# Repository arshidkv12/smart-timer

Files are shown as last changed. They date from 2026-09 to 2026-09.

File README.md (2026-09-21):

# Smart Timer Switch Using ESP8266 and RTC

A simple **Wi-Fi programmable timer switch** based on **ESP8266 and RTC**. It can automatically turn a connected device ON and OFF according to a configured schedule.

No internet connection is required. The timer creates its own local Wi-Fi network for configuration.

## Features

* 📡 ESP8266-based local Wi-Fi configuration
* ⏰ Real-time clock (RTC) for accurate timekeeping
* 🔌 5V relay for controlling electrical loads
* 🌐 Simple web-based configuration
* 🚫 No internet required
* 💾 Stores configuration locally
* 🔘 Physical button to enable configuration mode
* 📱 Configure using a mobile phone or computer

## Project Images

### Prototype

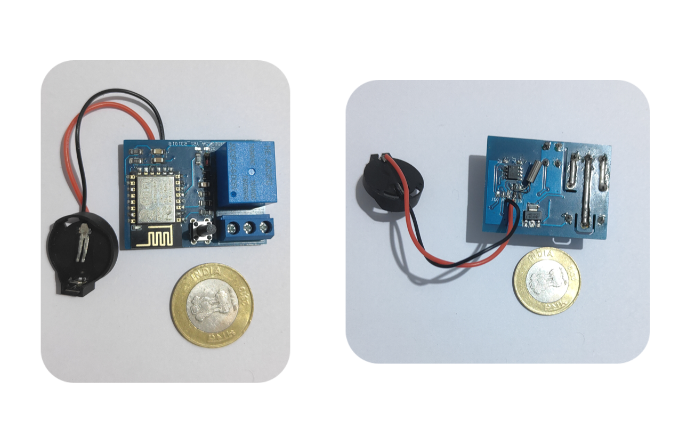
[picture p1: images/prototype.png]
Smart Timer Switch


### Circuit Diagram

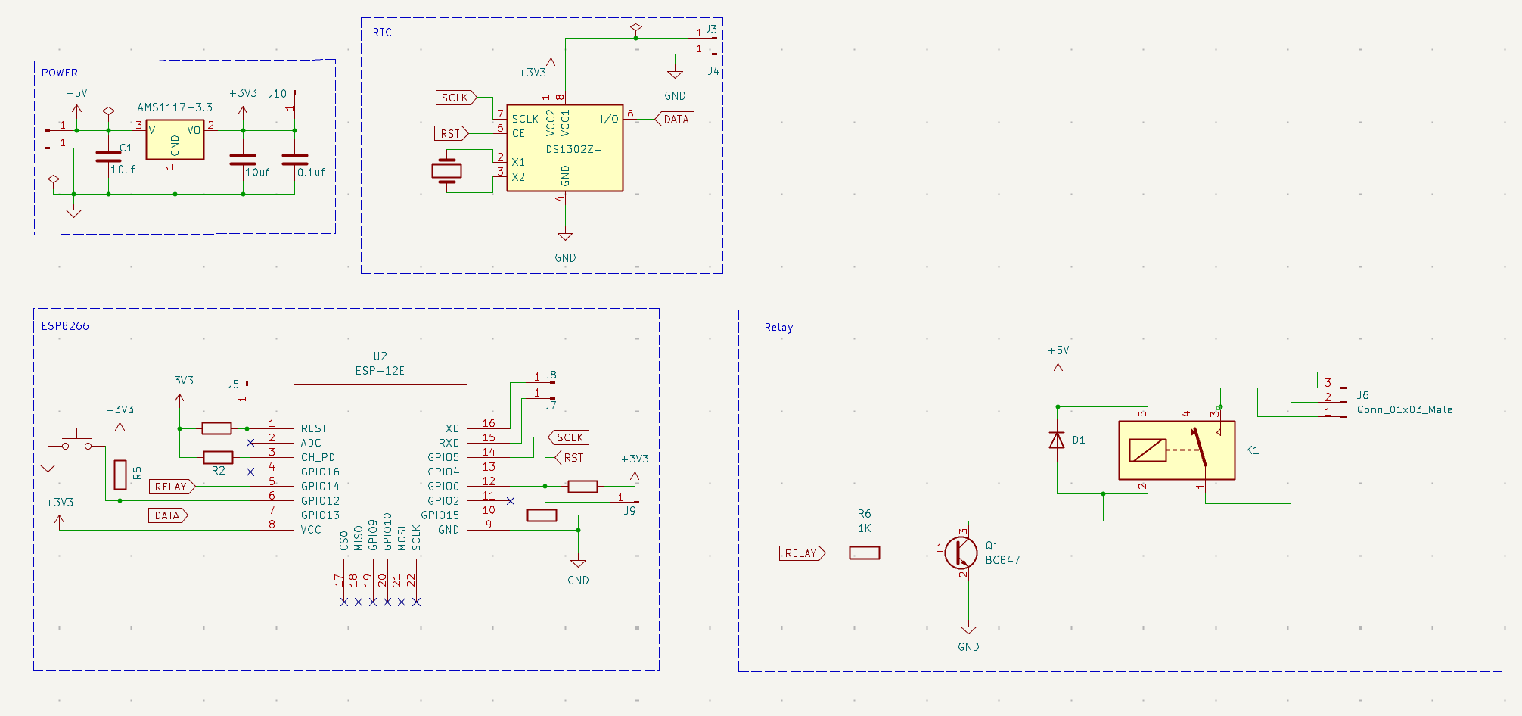
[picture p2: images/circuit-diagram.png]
Circuit Diagram


### Web Configuration

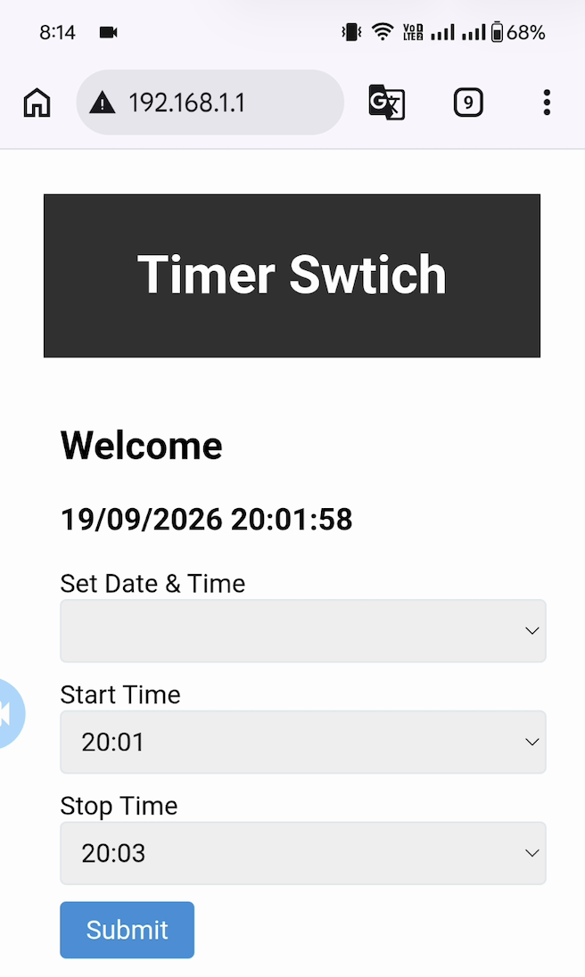
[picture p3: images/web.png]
Web Configuration


## YouTube

📺 **Watch the project demo:**  
▶️ [Watch the Smart Timer Switch Demo on YouTube](https://youtube.com/shorts/wJGOkK_HlXM)

## Main Blocks

The project mainly consists of four blocks:

1. **ESP8266** – Wi-Fi and controller
2. **5V Relay** – Controls the connected load
3. **Real-Time Clock (RTC)** – Keeps track of time
4. **Voltage Regulator** – Provides the required regulated voltage

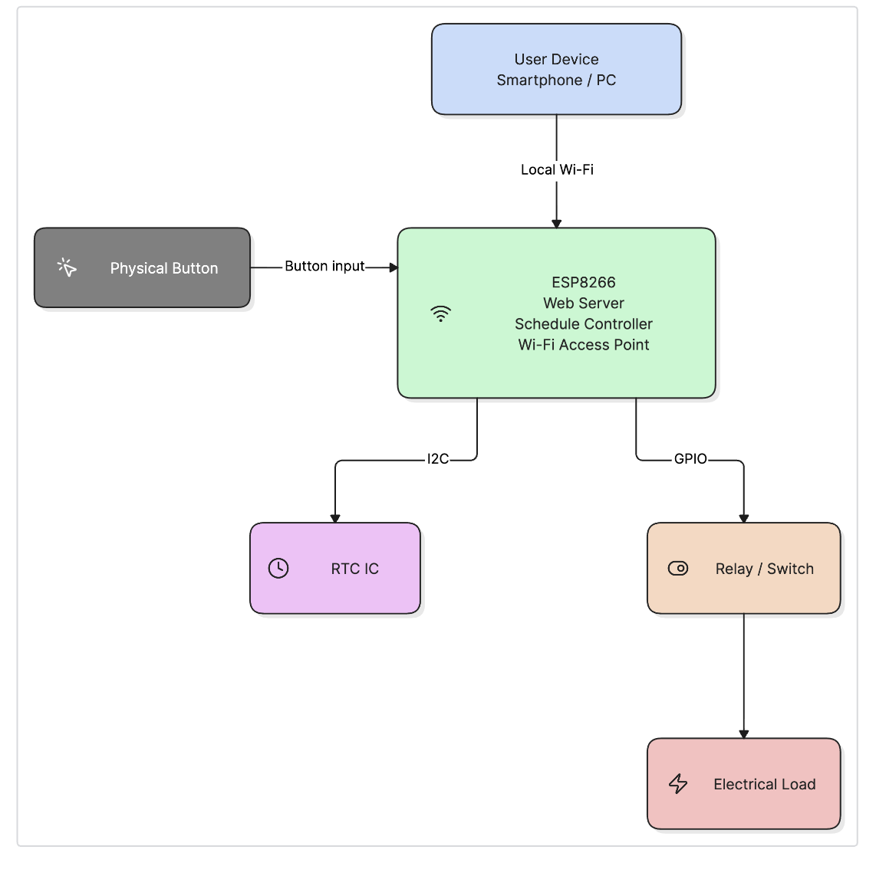
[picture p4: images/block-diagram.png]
Block Diagram


## How It Works

1. Power on the timer switch.
2. Press and hold the configuration button.
3. The ESP8266 enables local Wi-Fi mode.
4. Connect your phone or computer to the timer's Wi-Fi network.
5. Open a browser and go to:

```text
192.168.1.1
```

6. Set the current time if required.
7. Configure the ON and OFF schedule.
8. The timer automatically controls the connected load according to the schedule.

## Hardware

* ESP8266
* DS1302 RTC
* 5V Relay Module
* AMS1117-3.3V Voltage Regulator
* Push Button
* Resistors and capacitors
* Power supply
* Connected load

## Configuration

The timer uses a local web interface, so you don't need a cloud service or internet connection.

Connect to the timer's Wi-Fi, open `192.168.1.1` in your browser, and configure the required schedule.

## Example

For example:

```text
ON  → 08:01 PM
OFF → 08:03 PM
```

The relay will automatically switch the connected load according to the configured schedule.

## Advantages

* Simple configuration
* No internet dependency
* No LCD or LED display required
* Easy to modify the schedule
* Low-cost hardware
* Useful for automatic switching applications

## Project Structure

```text
├── firmware/
├── img/
│   ├── block-diagram.png
│   ├── diagram.png
│   ├── img.png
│   └── pcb.png
├── PCB/
├── README.md
└── project-report.pages
```

## License

This project is open source. See the `LICENSE` file for details.

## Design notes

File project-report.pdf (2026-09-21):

## Smart Offline Timer Switch: ESP8266-Based Programmable RTC Control

### Submitted By

## Muhammed Arshid KV

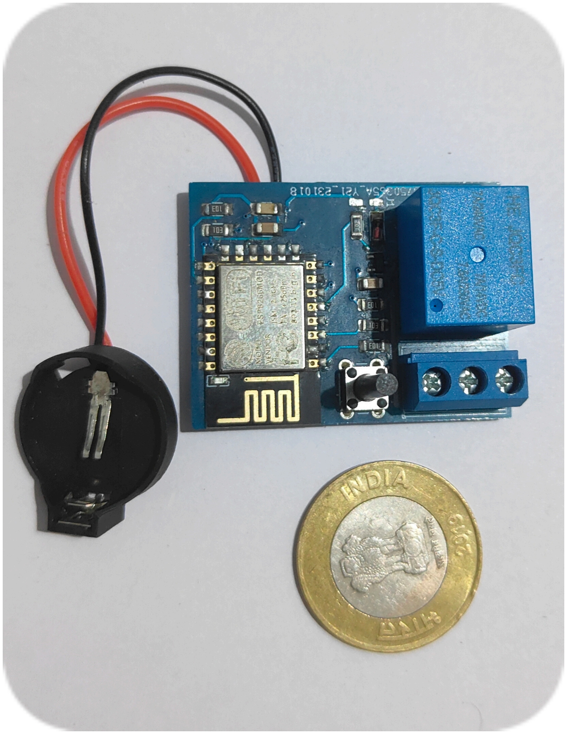
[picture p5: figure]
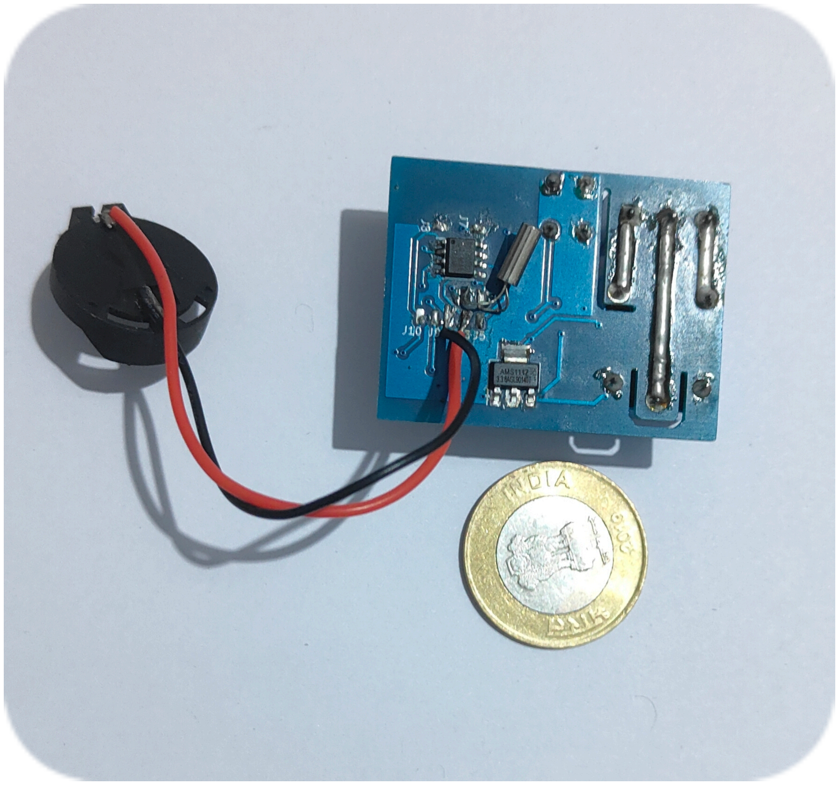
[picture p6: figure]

## 1. Abstract

This project presents the design and development of a Smart Programmable Timer Switch based on the ESP8266 microcontroller. The system is designed to control an electrical load according to user-defined schedules without requiring an internet connection.

Unlike conventional timer switches that use physical push-button configuration and 7-segment displays, configuring schedules through buttons can be difficult, while displays may require replacement over time. This system eliminates the need for a dedicated display by providing a simple web-based configuration interface.

The system operates completely offline. When configuration mode is activated by a long press of the physical button, the ESP8266 creates its own Wi-Fi access point. Users can connect directly to the device using a smartphone, tablet, or computer and access the web interface through: 192.168.1.1

Through the web interface, users can configure scheduled ON/OFF times and adjust the current RTC time when required.

A dedicated Real-Time Clock (RTC) IC maintains accurate time independently of the ESP8266's Wi-Fi connection or internet availability. Once the schedule is configured, the ESP8266 continuously monitors the RTC time and operates the connected electrical load according to the programmed schedule.

The system is suitable for applications such as lighting control, pumps, fans, agricultural equipment, aquarium systems, signage, and other appliances requiring scheduled operation.

## 2. Introduction

Automatic switching of electrical appliances at predefined times is useful in homes, commercial establishments, agriculture, and various industrial applications. Timer-based control can reduce manual effort and ensure that electrical loads operate according to a predetermined schedule.

Traditional timer switches are commonly configured using physical buttons, rotary controls, and small displays. Such interfaces can make schedule configuration inconvenient. Modern smart timer switches may provide more convenient smartphone-based control, but they often depend on internet connectivity, cloud services, mobile applications, user accounts, or continuous network availability.

The proposed system takes a different approach by providing simple local configuration without requiring the internet. The device uses an ESP8266 Wi-Fi microcontroller along with a dedicated Real-Time Clock (RTC) IC) to provide accurate time-based control.

To configure the device, the user simply presses and holds the physical button to activate configuration mode. The ESP8266 then creates its own Wi-Fi network, allowing a smartphone, tablet, or computer to connect directly to the device. The user can open a standard web browser and access the configuration interface at:

http://192.168.1.1

Through this interface, the user can configure the required ON/OFF schedules and adjust the RTC time when necessary. Since the device operates as its own Wi-Fi access point, no internet connection, mobile application, cloud account, or external Wi-Fi router is required for configuration.

Once the schedule is configured, the device can operate independently according to the programmed time settings, making it a practical solution for applications that require reliable and simple scheduled switching.

## 3. Objectives

The main objectives of this project are:

1. To develop an automatic programmable timer switch for scheduled electrical load control.
2. To eliminate the requirement for internet connectivity during configuration and operation.
3. To provide a simple browser-based interface for configuring the device.
4. To enable configuration using smartphones, tablets, or computers.
5. To use a dedicated RTC IC for accurate and reliable timekeeping.
6. To support multiple user-defined ON/OFF schedules.
7. To provide an option for manually adjusting the RTC time.
8. To minimize the number of physical controls required for configuration.
9. To eliminate the need for a dedicated display for schedule configuration.
10. To ensure that programmed schedules continue to operate even when the Wi-Fi configuration mode is inactive.
11. To develop a simple, reliable, and practical timer switch suitable for real-world applications.

## 4. Proposed System

The proposed system is a Smart Offline Programmable Timer Switch based on the ESP8266 microcontroller and a dedicated Real-Time Clock (RTC) IC. The system is designed to provide scheduled control of an electrical load without requiring an internet connection, external Wi-Fi router, or dedicated display.

The main components of the system are:

- ESP8266 microcontroller – Main controller of the system.
- RTC IC – Maintains the current date and time accurately.
- Switching circuit/relay – Controls the connected electrical load.
- Physical push button – Activates the configuration mode.
- Electrical load – The appliance or equipment controlled by the system.

The ESP8266 performs the following functions:

- Creates a local Wi-Fi access point for configuration.
- Hosts the configuration web interface.
- Receives user-defined schedules through the web interface.
- Reads the current date and time from the RTC.
- Stores and manages the programmed schedules.
- Compares the RTC time with the programmed schedules.
- Controls the switching circuit according to the scheduled ON/OFF times.

The RTC IC provides the current date and time independently of the Wi-Fi connection. After the

schedules are configured, the system can operate automatically based on the stored schedule even

when the configuration Wi-Fi mode is inactive.

When the physical button is pressed and held, the ESP8266 enters configuration mode and creates

its own Wi-Fi network. The user can connect to this network using a smartphone, tablet, or

computer and access the web-based configuration interface to set schedules or adjust the RTC time.

Basic architecture

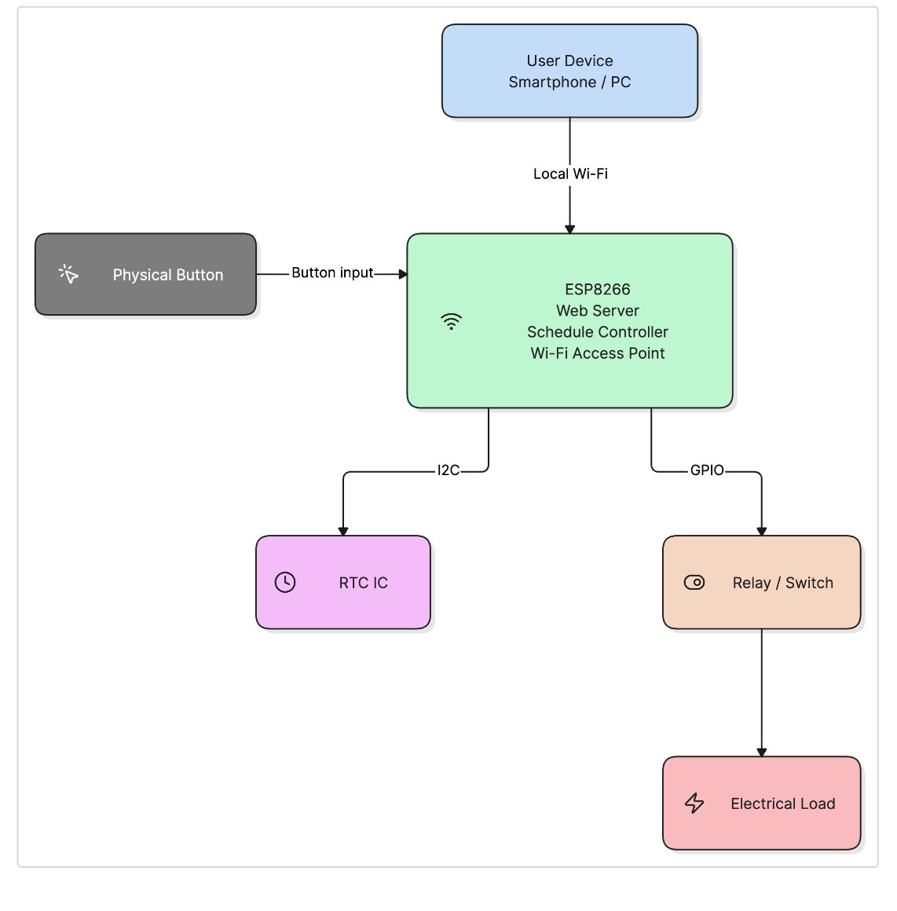
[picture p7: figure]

## 5. Hardware Components

The exact RTC IC and switching component can be specified according to the hardware version of the project.

## 6. Software Components

The software consists of several major modules.

ESP8266 firmware

The firmware is responsible for:

- Initializing hardware
- Reading the RTC
- Managing schedules
- Controlling the output
- Detecting long button presses
- Starting/stopping Wi-Fi configuration mode
- Running the web server
- Saving configuration data
Component | Function
ESP 8266 | Main microcontroller and Wi-Fi interface
RTC IC | Maintains accurate date and time
Relay / switching circuit | Controls the electrical load
Push button | Activates configuration mode
Power supply | Provides power to the electronics
RTC backup battery | Maintains RTC time during power interruptions
Electrical load | Appliance or device being controlled

Web interface

The embedded web server provides pages for:

- Current time
- RTC adjustment
- Schedule configuration
- ON/OFF settings
- Device status
- Configuration mode

The interface can be accessed using a normal web browser.

No dedicated Android or iOS application is required.

## 7. Operating Principle

The system operates in two primary modes.

Normal Operating Mode

During normal operation:

1. ESP8266 initializes the system.
2. The RTC provides the current time.
3. ESP8266 reads the programmed schedules.
4. The current time is compared with the schedule.
5. The output is switched ON or OFF accordingly.
6. Wi-Fi configuration mode remains inactive.
Therefore, the device can perform its main timer function without being connected to a network.

Configuration Mode

To configure the device:

1. The user presses and holds the physical button.
2. The ESP8266 detects the long press.
3. Configuration Wi-Fi is activated.
4. The ESP8266 creates its own wireless network.
5. The user connects a smartphone, tablet, or computer to the device.
6. The user opens a browser.
7. The user accesses 192.168.1.1.
8. The configuration page is displayed.
9. The user modifies schedules or RTC time.
10. The settings are stored.
11. Configuration mode can then be exited.

## 8. Offline Wi-Fi Configuration

One of the key features of the project is its internet-independent configuration system.

The ESP8266 works as a local access point.

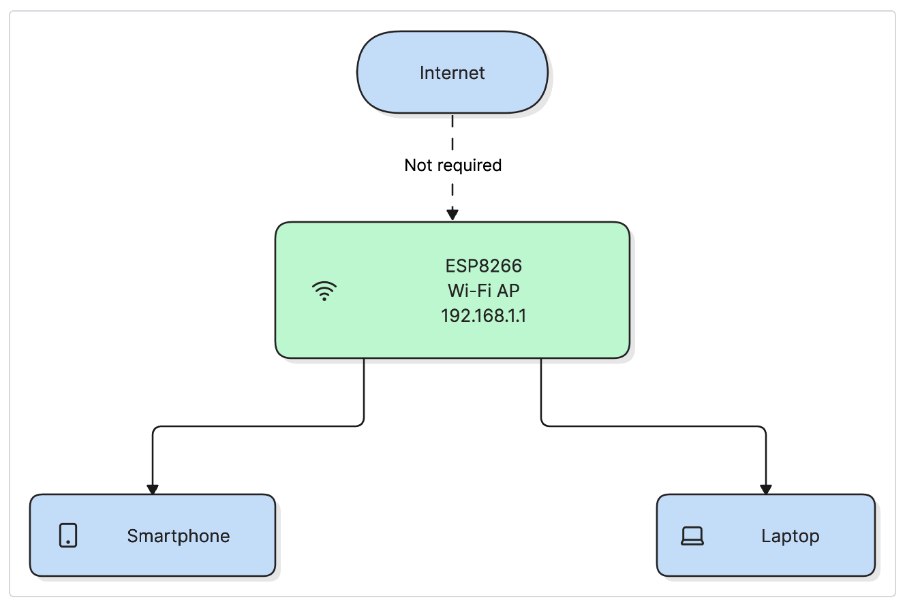
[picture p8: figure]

This means the user does not need:

- Internet
- Home Wi-Fi router
- Cloud server
- Mobile application
- Remote server
The phone communicates directly with the ESP8266.

## 9. Schedule Configuration

The user can define scheduled events through the web interface.

For example:

The ESP8266 continuously compares the RTC time with these programmed events.

For example:

06:00 ───── ON
08:00 ───── OFF
18:00 ───── ON
22:00 ───── OFF

This allows the same device to automatically control a load every day according to the programmed schedule.

## 10. RTC Time Adjustment

The RTC IC is an important part of the system because scheduled switching depends on accurate time.

The web interface provides an option to adjust the RTC time.

Schedule | Time | Action
1 | 06:00 | ON
2 | 08:00 | OFF
3 | 18:00 | ON
4 | 22:00 | OFF

The user can correct the RTC time whenever necessary.

The RTC's backup battery allows the clock to continue maintaining time when the main power supply is temporarily unavailable, depending on the RTC hardware used.

## 11. Long-Press Configuration Mechanism

A single physical button can be used to activate configuration mode.

Instead of keeping Wi-Fi active continuously, the device detects a long press.

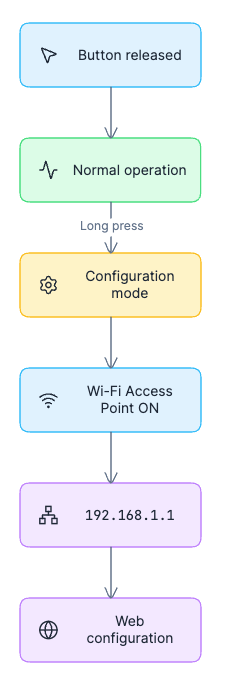
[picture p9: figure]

This approach has several benefits:

- Fewer physical controls
- Simple user interface
- Wi-Fi does not need to remain active
- Lower unnecessary power consumption
- Reduced exposure of the configuration interface during normal operation

## 12. Advantages

### 12.1 Internet-Independent Operation

The system does not require an internet connection for configuration or normal operation. This allows the timer to function independently in locations where internet access is unavailable.

### 12.2 Browser-Based Configuration

The timer can be configured using a standard web browser on a smartphone, tablet, laptop, or computer with Wi-Fi capability.

### 12.3 No Dedicated Mobile Application

No special mobile application needs to be installed. The web-based interface can be accessed directly through a standard browser.

### 12.4 Direct Local Communication

Communication takes place directly between the user's device and the ESP8266 through its local Wi-Fi network. No cloud server or external router is required.

### 12.5 RTC-Based Accurate Timing

A dedicated Real-Time Clock (RTC) IC provides reliable timekeeping for accurate execution of programmed schedules.

### 12.6 Simple Configuration

A physical long-press button is used to activate configuration mode, providing a simple method of accessing the web interface without requiring multiple physical buttons or a dedicated display.

### 12.7 Automatic Operation

After the required schedules are programmed, the system automatically controls the connected electrical load according to the configured ON/OFF times without continuous user intervention.

### 12.8 Low-Cost Implementation

The ESP8266 integrates Wi-Fi functionality and microcontroller capabilities into a compact and relatively low-cost platform, reducing the overall hardware complexity of the system.

### 12.9 No Dedicated Display Required

The web-based interface eliminates the need for a dedicated display such as a 7-segment display for configuring and viewing timer settings, reducing hardware requirements and simplifying the design.

## 13. Applications

The Smart Offline Programmable Timer Switch can be used in a wide range of applications where scheduled control of electrical equipment is required. Possible applications include:

- Home and garden lighting
- Automatic water pumps
- Aquarium equipment
- Fans and ventilation systems
- Shop and commercial lighting
- Signboards and display lighting
- Agricultural equipment
- Irrigation systems
- Poultry equipment
- Greenhouse equipment
- Decorative lighting
- Industrial auxiliary equipment
- Battery charging systems
- Energy-saving automation
- Other electrical appliances requiring scheduled ON/OFF operation

## 14. Security Considerations

Since the configuration interface is accessible through a local Wi-Fi network, appropriate security measures should be considered to prevent unauthorized configuration.

Possible security measures include:

- Enable configuration mode only after a long press of the physical button.
- Use a configurable password for the Wi-Fi access point.
- Protect the web interface using authentication.
- Automatically disable configuration mode after a predefined timeout.
- Validate all values received through the web interface.
- Prevent unauthorized or arbitrary commands from being executed through HTTP parameters.
- Restrict configuration requests to the local device.
- Provide a physical reset mechanism when required.

The configuration Wi-Fi can also be automatically disabled after a predefined period of inactivity, reducing the time during which the configuration interface is accessible.

## 15. Reliability

A major design objective of the system is that scheduled timer operation should not depend on Wi-Fi or internet availability.

The architecture can therefore be divided into two independent functions:

### 15.1 Configuration Function

The ESP8266 provides a local Wi-Fi access point and web interface only when configuration mode is activated. The user can configure schedules and adjust the RTC time through a web browser.

### 15.2 Timer Control Function

The RTC continuously maintains the current time, while the ESP8266 compares the RTC time with the programmed schedules and controls the switching circuit accordingly. Once the configuration mode is disabled, the timer can continue its scheduled operation without an active Wi-Fi connection.

This separation improves the reliability of the system because temporary unavailability of Wi-Fi does not prevent the programmed timer from controlling the connected electrical load.

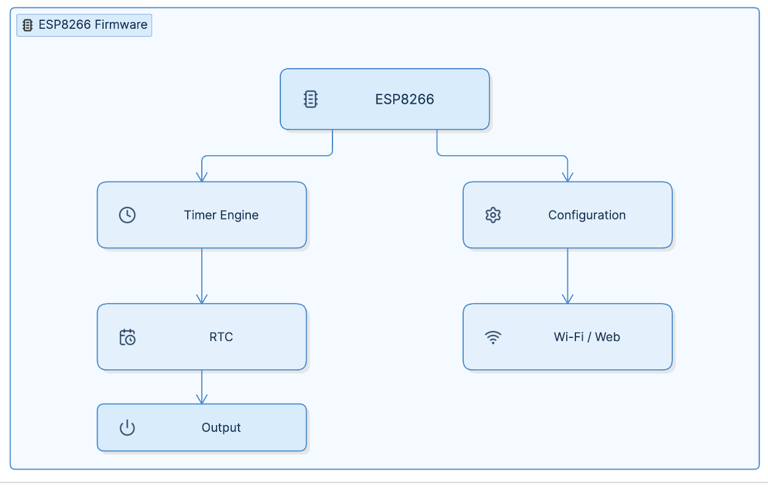
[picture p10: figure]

## 16. Limitations

Some limitations of the current design may include:

1. The user must be physically near the device to configure it.
2. Remote control is not available unless additional networking functionality is implemented.
3. RTC accuracy depends on the selected RTC IC and its oscillator.
4. The maximum number of schedules depends on firmware and available memory.
5. The electrical switching circuit must be appropriately rated for the connected load.
6. Mains-voltage hardware requires appropriate electrical isolation and safety precautions.

## 17. Future Improvements

The project can be extended with several features.

Multiple outputs

The system could control multiple relays independently.

Weekly schedules

Different schedules could be configured for Monday–Sunday.

Holiday/date-specific schedules

Specific dates could have different switching behavior.

Sunrise/sunset scheduling

The device could calculate switching times based on location and date, although this would require additional configuration/data.

Energy monitoring

Current and voltage sensors could be added to measure power consumption.

Manual control

The physical button could also provide manual ON/OFF control.

Configuration backup

Schedules could be exported and imported through the web interface.

Password protection

The configuration interface could require a username/password or PIN.

## 18. Conclusion

The Smart Offline Programmable Timer Switch using ESP8266 and RTC demonstrates how modern embedded technology can be used to provide convenient web-based configuration without depending on the internet or cloud services.

The ESP8266 provides the processing capability and local Wi-Fi connectivity, while the RTC IC provides reliable timekeeping for scheduled operation. A long-press physical button provides a simple method for entering configuration mode. Once activated, users can connect directly to the device using a smartphone, tablet, or computer and configure the timer through a standard web browser at 192.168.1.1.

The system combines embedded control, local Wi-Fi communication, web-based configuration, real-time clock functionality, and scheduled switching into a compact and practical solution. Since normal timer operation does not require an active Wi-Fi connection or internet access, the system can continue executing programmed schedules independently.

The elimination of a dedicated display and multiple configuration buttons also simplifies the hardware design and provides a more convenient configuration method through a web browser.

Project Highlights

ESP8266 + RTC + Local Web Interface + Scheduled Switching + No Internet Required

The core concept of the project can be summarized as:

“A Wi-Fi programmable timer that works without the internet.”

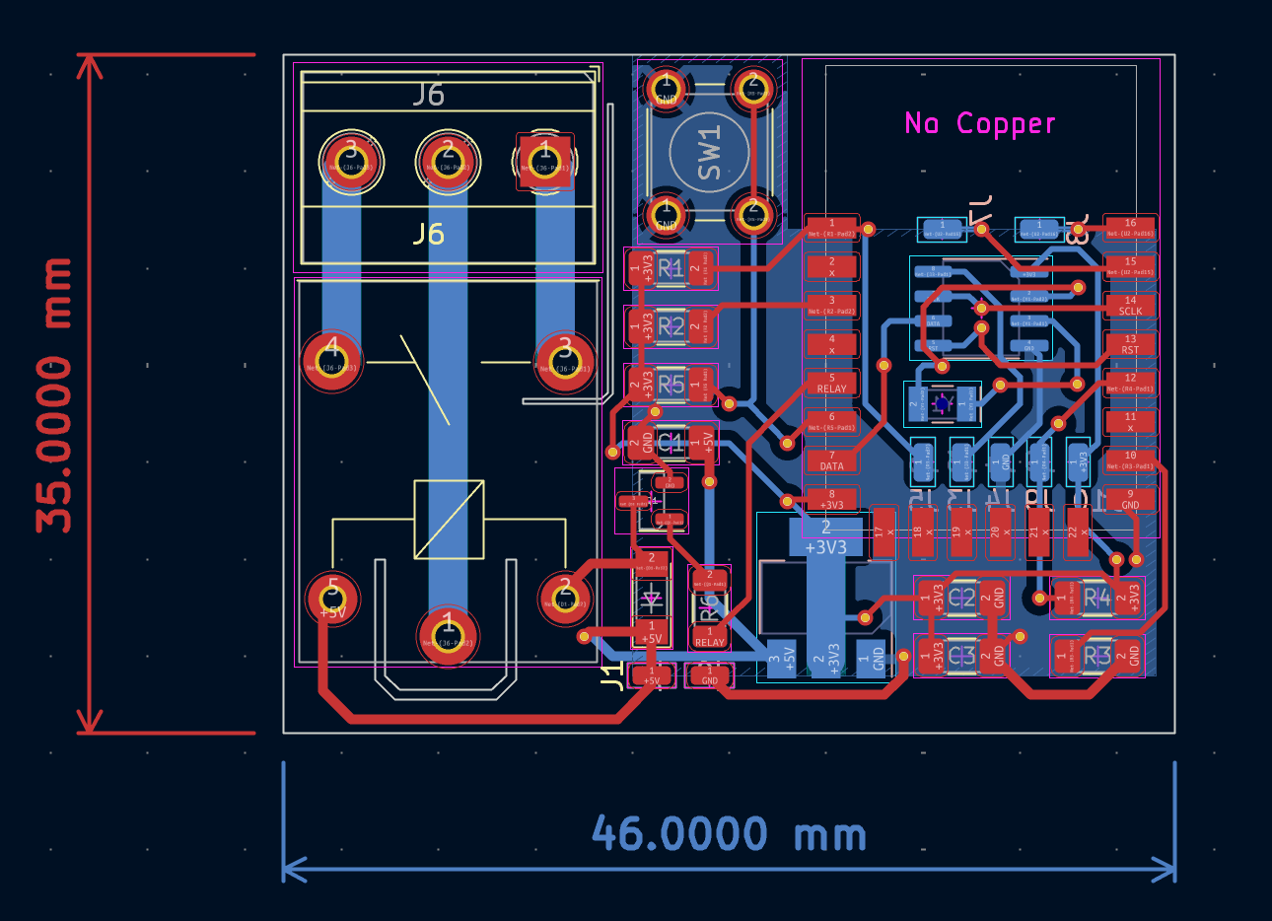
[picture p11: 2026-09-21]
images/pcb.png

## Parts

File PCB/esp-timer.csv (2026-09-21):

Comment | Designator | Footprint | LCSC Part #
10uf Unpolarized capacitor | C1,C2 | C_1206_3216Metric_Pad1.33x1.80mm_HandSolder
0.1uf Unpolarized capacitor | C3 | C_1206_3216Metric_Pad1.33x1.80mm_HandSolder
1N4007 1000V 1A General Purpose Rectifier Diode, DO-41 | D1 | D_MiniMELF
Conn_01x01_Male Generic connector, single row, 01x01, script generated (kicad-library-utils/schlib/autogen/connector/) | J1,J2,J3,J4,J5,J7,J8,J9,J10 | SolderWirePad_1x01_SMD_1x2mm
Conn_01x03_Male Generic connector, single row, 01x03, script generated (kicad-library-utils/schlib/autogen/connector/) | J6 | TerminalBlock_Phoenix_MKDS-1,5-3_1x03_P5.00mm_Horizontal
SANYOU_SRD_Form_C Sanyo SRD relay, Single Pole Miniature Power Relay, | K1 | Relay_SPDT_SANYOU_SRD_Series_Form_C
BC847 0.1A Ic, 45V Vce, Small Signal NPN Transistor, TO-92 | Q1 | SOT-23
R Resistor | R1,R2,R3,R4,R5 | R_1206_3216Metric_Pad1.30x1.75mm_HandSolder
1K Resistor | R6 | R_1206_3216Metric
SW_Push Push button switch, generic, two pins | SW1 | SW_PUSH_6mm_H13mm
AMS1117-3.3 1A Low Dropout regulator, positive, 3.3V fixed output, SOT-223 | U1 | SOT-223-3_TabPin2
ESP-12E ESP8266 ESP-12E module, 22 pins, 2mm, PCB antenna | U2 | ESP-12E_SMD
DS1302Z+ Trickle-Charge Timekeeping Chip, 2.0V to 5.5V VCC, 0°C to +70°C, SOIC-8 | U3 | SOIC-8_3.9x4.9mm_P1.27mm
Crystal Two pin crystal | Y1 | Crystal_SMD_G8-2Pin_3.2x1.5mm

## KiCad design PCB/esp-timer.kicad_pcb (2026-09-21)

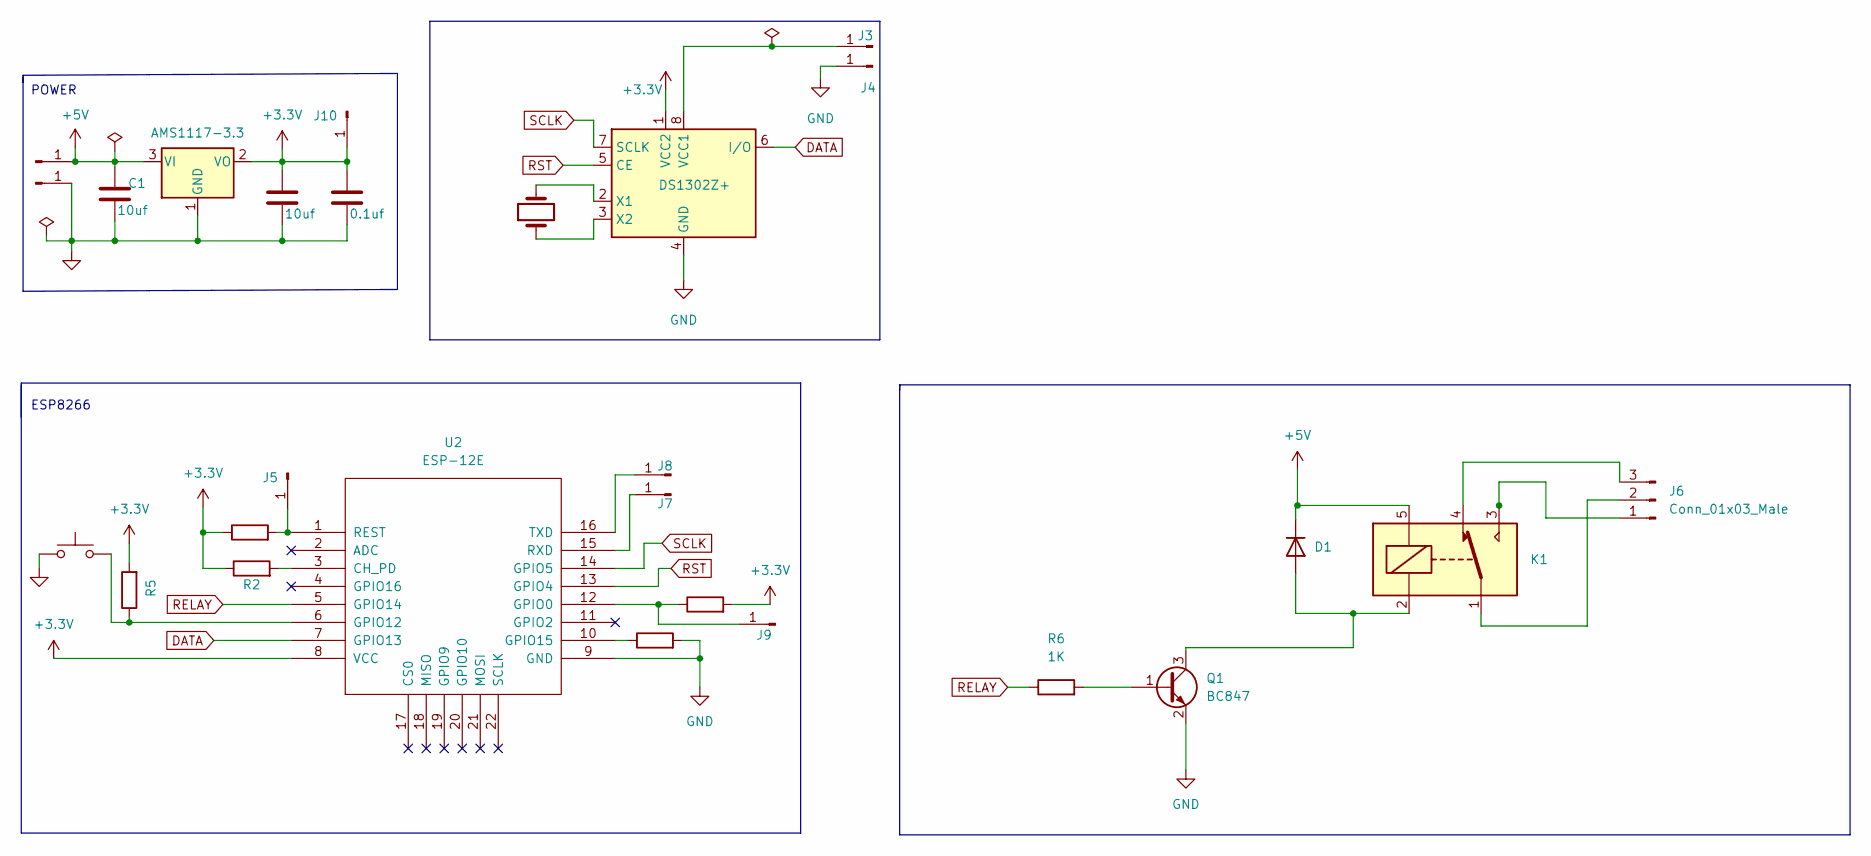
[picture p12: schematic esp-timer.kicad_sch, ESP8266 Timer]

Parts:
C1, C2: 10uf; C_1206_3216Metric_Pad1.33x1.80mm_HandSolder
C3: 0.1uf; C_1206_3216Metric_Pad1.33x1.80mm_HandSolder
D1: 1N4007; D_MiniMELF
J1, J2, J3, J4, J5, J7, J8, J9, J10: Conn_01x01_Male; SolderWirePad_1x01_SMD_1x2mm
J6: Conn_01x03_Male; TerminalBlock_Phoenix_MKDS-1,5-3_1x03_P5.00mm_Horizontal
K1: SANYOU_SRD_Form_C; Relay_SPDT_SANYOU_SRD_Series_Form_C
Q1: BC847; SOT-23
R1, R2, R3, R4, R5: R; R_1206_3216Metric_Pad1.30x1.75mm_HandSolder
R6: 1K; R_1206_3216Metric
SW1: SW_Push; SW_PUSH_6mm_H13mm
U1: AMS1117-3.3; SOT-223-3_TabPin2
U2: ESP-12E; ESP-12E_SMD
U3: DS1302Z+; SOIC-8_3.9x4.9mm_P1.27mm
Y1: Crystal; Crystal_SMD_G8-2Pin_3.2x1.5mm

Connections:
+3V3: C2.1, C3.1, J10.1, R1.1, R2.1, R4.2, R5.2, U1.2 (VO), U2.8 (VCC), U3.1 (VCC2)
+5V: C1.1, D1.1 (K), J1.1, K1.5, U1.3 (VI)
DATA: U2.7 (GPIO13), U3.6 (I/O)
GND: C1.2, C2.2, C3.2, J2.1, J4.1, Q1.2 (E), R3.2, SW1.1, U1.1 (GND), U2.9 (GND), U3.4 (GND)
unnamed: D1.2 (A), K1.2, Q1.3 (C)
unnamed: J3.1, U3.8 (VCC1)
unnamed: J6.1, K1.3
unnamed: J6.2, K1.1
unnamed: J6.3, K1.4
unnamed: Q1.1 (B), R6.2
unnamed: J5.1, R1.2, U2.1 (REST)
unnamed: R2.2, U2.3 (CH_PD)
unnamed: R3.1, U2.10 (GPIO15)
unnamed: J9.1, R4.1, U2.12 (GPIO0)
unnamed: R5.1, SW1.2, U2.6 (GPIO12)
unnamed: J7.1, U2.15 (RXD)
unnamed: J8.1, U2.16 (TXD)
unnamed: U3.3 (X2), Y1.1
unnamed: U3.2 (X1), Y1.2
RELAY: R6.1, U2.5 (GPIO14)
RST: U2.13 (GPIO4), U3.5 (CE)
SCLK: U2.14 (GPIO5), U3.7 (SCLK)

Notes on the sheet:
POWER
ESP8266

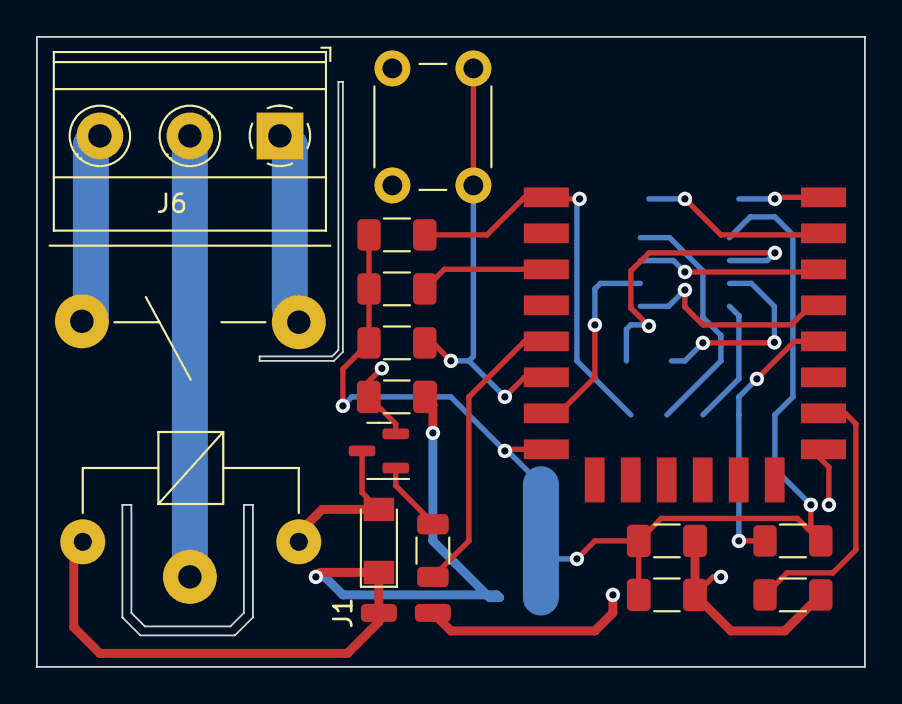
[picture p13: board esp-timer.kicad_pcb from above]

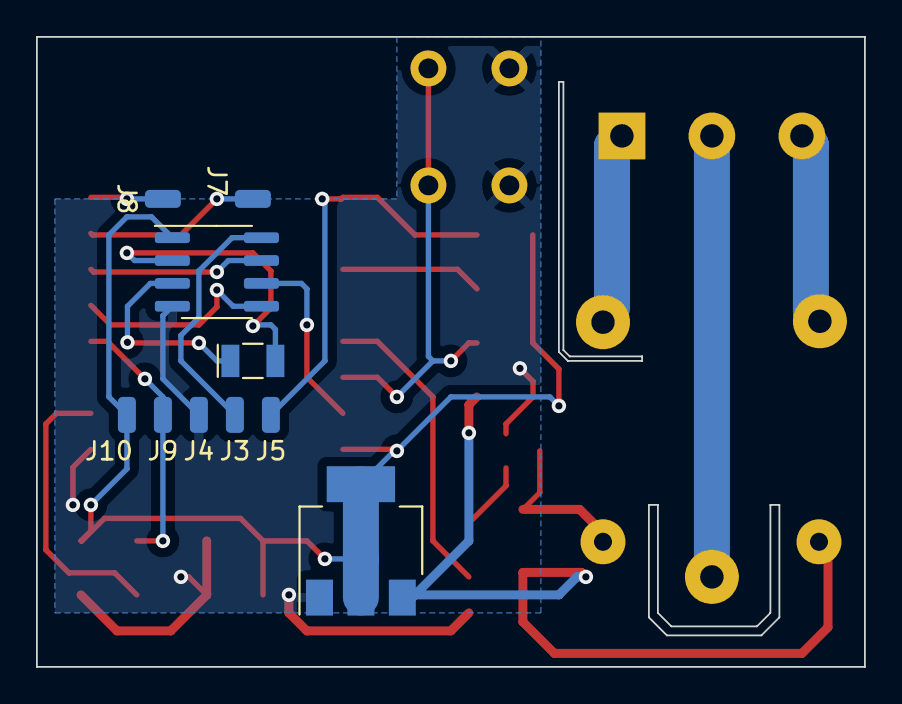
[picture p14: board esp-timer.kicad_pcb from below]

Board: 2 copper layers, 46.0 x 35.0 mm, 27 parts (10 on the bottom side), 22 nets.

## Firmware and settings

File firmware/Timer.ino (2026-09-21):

#include <EEPROM.h>
#include "WebServer.h"
#include "func.h"
#include "watch.h"


unsigned long buttonLowTime = 0;
const int button            = 12;

void setup() {
    //Serial.begin(9600);
    pinMode(button, INPUT);
    pinMode(relay_pin, OUTPUT);

    EEPROM.begin(512);  
}


void loop() {
  
  unsigned long currentMillis = millis();

  delay(100);
  int input = digitalRead(button);
  if(input == 0 ){
      buttonLowTime = currentMillis;
      SetupWebServer();
      delay(200);
  }


  if( (  currentMillis - buttonLowTime ) < 600000 ){ //10 min
    dnsServer.processNextRequest();
    webServer.handleClient();
  }else{
    stopWebServer();
  }

  watchLoop();

}
